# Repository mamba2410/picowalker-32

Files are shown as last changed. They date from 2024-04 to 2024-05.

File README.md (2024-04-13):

# picowalker-32

Thsi repo contains all the designs, schematics, pcb layouts and code for the *picowalker-32* project.

The *picowalker-32* is a modern, open source and faithful recreation of the *Pokewalker* from *Pokemon HeartGold/SoulSilver*.
The goal is to have a device that fully mimics the features and functionality of a *Pokewalker*, except made with modern 
features such as a rechargeable battery, colour screen and an additional flash memory chip to store more data.

The *picowalker-32* is based on the STM32U535 chip, which has far more ram, flash and computing capabilities than the original
processor. Most importantly, its available to purchase, even in small quantities.
Due to the lack of options for screens and batteries, the *picowalker-32* is slightly larger than the original *Pokewalker*.

The software in this repo is designed to be enough to run the [picowalker-core]() code to fully simulate a *Pokewalker*,
however, theres no reason that other software can't be run on it!

The name *picowalker-32* comes from the original *picowalker* concept, a [mintyPi](https://sudomod.com/mintypi-v3-5/) inspired
pokewalker, based on the [Raspberry Pi Pico](https://www.raspberrypi.com/products/raspberry-pi-pico/), hence the *pico* in the name.
The project later evolved into a custom-PCB solution using an STM32 controller for lower power draw. Hence the *-32* suffix.

## What's in this repo

- Design files for the schematics and PCB layout, drawn in KiCAD 7.
- STM32CubeMX configuration for the STM32U545 chip used in the design.
- STM32 code using the STM32 HAL for the drivers and dependencies that the [picowalker-core](https://github.com/mamba2410/picowalker-core) needs to function.
- Developer notes and a bill of materials used in testing.
- Other, miscellaneous notes related to the *picowalker-32* project.

## The state of the project

Currently, the project is in active development.
There are schematics, the start of some code and materials that have been picked out.
The project is being prototyped on a breadboard using the *NUCLEO-U545RE* development board and other
breakout boards for fast prototyping.

Left to do:

- Finish the schematics (power delivery, other checks).
- Finish the driver for the screen.
- Start drivers for the IR, accelerometer, eeprom, flash memory, sound, buttons and others.
- Route the PCB (either a test PCB or directly onto the final form factor).
- Manufacture and test the PCB and iterate on it.

## Development and Contribution

If you want to help develop this project, make sure to read the [development document](./development.md) for instructions 
on how to recreate the project at home.

I encourage you to come join the [Discord](https://discord.gg/dVVnM6f5tP)! This is where most of the discussion happens about the project.
There's also other stuff related to the *Pokewalker* including reverse enginnering and hacking it.

Thanks to all the contributors who have helped out a lot, especially

- Kamp, for doing all the CAD work for the shells, picking out components like the screen and battery (which were really hard to find!) and others.
- Zenith, for help with sprites and images and even recreating most of the coloured ones to work on the walker.
- PoroCYon, for help with schematics, electrical questions and picking a suitable MCU.

## Licensing

I'm not sure about the license, I want this project to be as open and accessible as possible.

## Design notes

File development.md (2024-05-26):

# Developing the picowalker-32

This document contains materials and instructions to help with developing this project.

## Hardware

List of hardware I'm currently using to prototype on a breadboard:

- [NUCLEO-U545RE Nucleo-64 development board](https://www.st.com/en/evaluation-tools/nucleo-u545re-q.html)
- [dwo DO0180PFST05 AMOLED screen](https://www.dwo.net.cn/pd.jsp?fromColId=2&id=11924#_pp=2_2452)
- [Sparkfun BMA400 breakout board](https://www.sparkfun.com/products/21208) (in SPI mode)
- [Mikroe IrDA 3-click Serial-to-IrDA breakout board](https://www.mikroe.com/irda-3-click)
    - Note: any normal IR transceiver will work when directly driven by the STM32
- [Huawei P8 phone speaker](https://www.aliexpress.us/item/2251832745770085.html)
    - Note: this part isn't finalised until we can get it working
- Some SPI EEPROM. Note: this may be removed in the future
    - [M95512 64k (SMD)](https://www.mouser.co.uk/ProductDetail/STMicroelectronics/M95512-DWDW4TP-K?qs=gNDSiZmRJS8kMWQ2whknqA%3D%3D)
    - [25LC512 64k (SMD, breadboard)](https://ww1.microchip.com/downloads/aemDocuments/documents/MPD/ProductDocuments/DataSheets/25LC512-512-Kbit-SPI-Bus-Serial-EEPROM-Data-Sheet-20002065.pdf)
- Some SPI/QSPI 128Mbit flash
    - [IS25WP128 (1.8V, SMD)](https://www.mouser.co.uk/ProductDetail/ISSI/IS25WP128F-JBLE?qs=W0yvOO0ixfF8aDjNpplUZA%3D%3D)

## Software

All software development (except CubeMX stuff) has been done on linux, I don't know how to build and debug on
Windows, sorry.

- [KiCad 7.0](https://www.kicad.org/) for the schematics and PCB layouts (haven't tested with 8.0).
- [SamacSys Library Loader](https://www.samacsys.com/library-loader/) for KiCad models and schematics.
- [STM32CubeMX VERSION 6.10](https://www.st.com/en/development-tools/stm32cubemx.html) for pinout and STM32 MCU initialisation and HAL.
- Neovim/VSCode for all other programming.
- CMake/GNU make for building.
- Linux/WSL for compiling and debugging the code.
- [stlink](https://github.com/stlink-org/stlink) and gdb for on-chip debugging.

## Notes on STM32 stuff

- SPI mode check "Master keep IO state enable" otherwise it fiddles with the clock and misses the first
  bit.

## Guide

Guide is yet to come.

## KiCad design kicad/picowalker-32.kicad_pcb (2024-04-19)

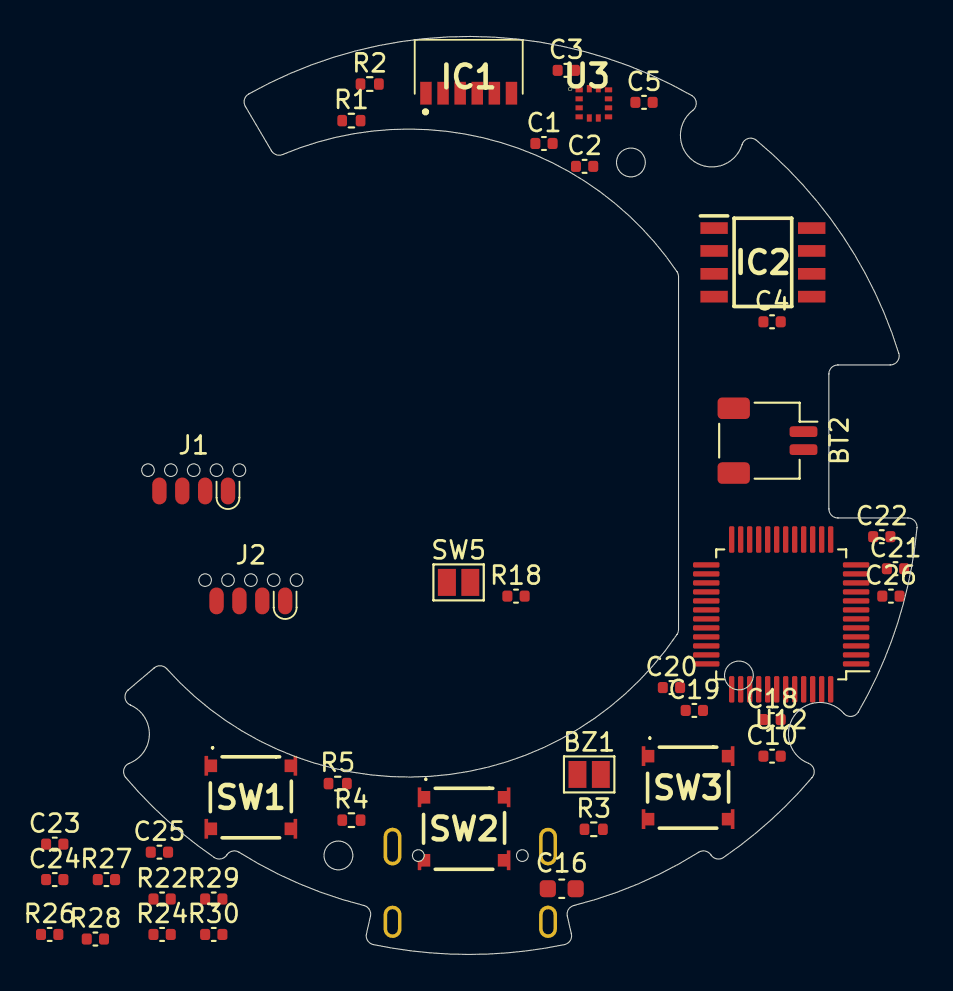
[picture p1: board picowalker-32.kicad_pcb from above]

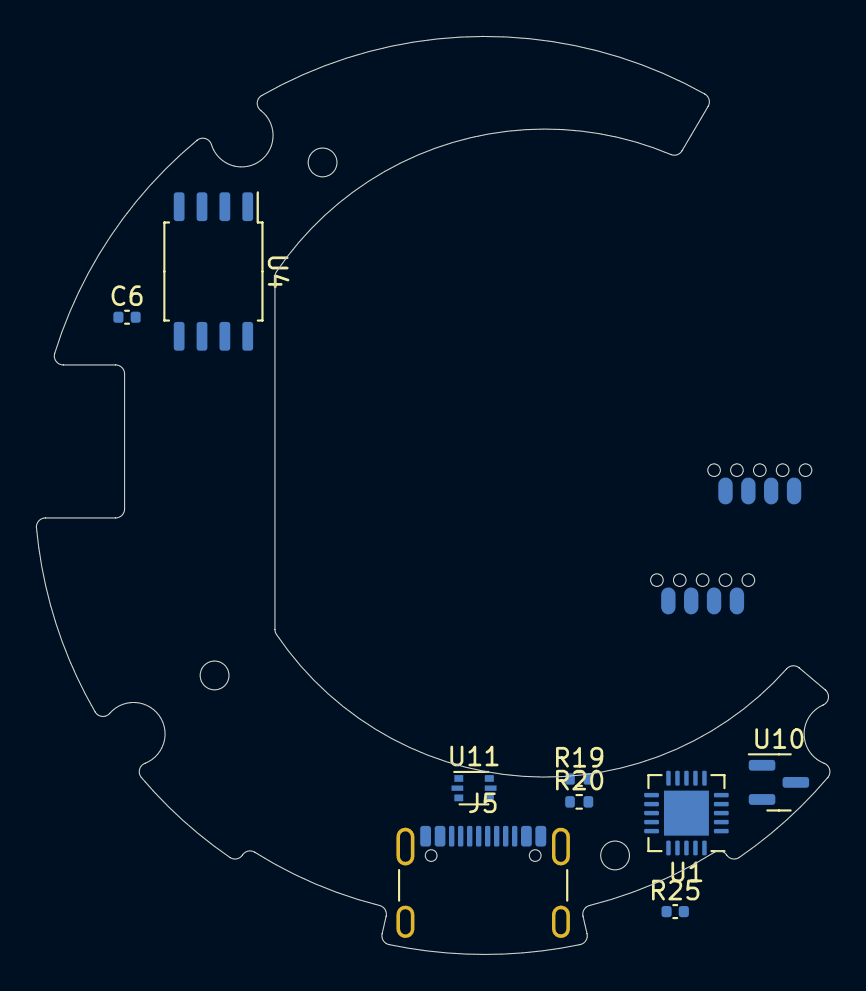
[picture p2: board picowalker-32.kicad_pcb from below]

Board: 2 copper layers, 44.1 x 51.0 mm, 50 parts (9 on the bottom side), 47 nets, no tracks yet.

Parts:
BT2: LPR553535A; JST_SH_SM02B-SRSS-TB_1x02-1MP_P1.00mm_Horizontal
BZ1: Speaker; SolderJumper-2_P1.3mm_Open_Pad1.0x1.5mm
C1, C3, C4, C5, C6: 0.1uF; C_0402_1005Metric
C2, C26: 4.7uF; C_0402_1005Metric
C10, C18, C19, C21: 100nF; C_0402_1005Metric
C16: C; C_0603_1608Metric
C20, C23, C24, C25: 10uF; C_0402_1005Metric
C22: 1uF; C_0402_1005Metric
IC1: TFBS4711-TT1; TFBS4711TT1
IC2: M95512-DRMN8TP_K; SOIC127P600X175-8N
J1: DBG_HDR; SOIC_clipProgSmall
J2: PROGRAM_HDR; SOIC_clipProgSmall
J5: USB_C_Receptacle_USB2.0; USB_C_Receptacle_GCT_USB4105-xx-A_16P_TopMnt_Horizontal
R1: 56R; R_0402_1005Metric
R2: 47R; R_0402_1005Metric
R3, R4, R5: 100k; R_0402_1005Metric
R18, R26: 10k; C_0402_1005Metric
R19, R20: 5k1; R_0402_1005Metric
R22, R24, R25: 100k; C_0402_1005Metric
R27: 20k; C_0402_1005Metric
R28: R; C_0402_1005Metric
R29: 330k; C_0402_1005Metric
R30: 110k; C_0402_1005Metric
SW1, SW2, SW3: SW_Push; TL3315NF100Q
SW5: BOOTSEL; SolderJumper-2_P1.3mm_Open_Pad1.0x1.5mm
U1: MCP73871; QFN-20-1EP_4x4mm_P0.5mm_EP2.5x2.5mm
U3: BMA400; BOSCH_LGA-12
U4: W25Q128JVS; SOIC-8_5.23x5.23mm_P1.27mm
U10: MCP1700x-180xxTT; SOT-23
U11: USBLC6-2P6; SOT-666
U12: STM32U535CET6-modified; LQFP-48_7x7mm_P0.5mm

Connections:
+1V8: C10.2, C18.2, C19.2, C20.2, C21.2, C22.2, R22.2, R24.2, R25.2, SW5.1, U10.2 (VO), U12.1 (VBAT), U12.7 (NRST), U12.9 (VDDA), U12.24 (VDD), U12.36 (VDD), U12.48 (VDD)
/power-control-1.8V/BAT+: BT2.1 (+), C23.1, U1.14 (V_{BAT}), U1.15 (V_{BAT}), U1.16 (V_{BAT_SENSE})
/power-control-1.8V/PWR_SRC: C24.2, U1.1 (OUT), U1.20 (OUT), U10.3 (VI)
/power-control-1.8V/USB_5V: C16.1, C25.2, J5.A4 (VBUS), J5.A9 (VBUS), J5.B4 (VBUS), J5.B9 (VBUS), R29.1, U1.9 (~TE), U1.17 (CE), U1.18 (IN), U1.19 (IN), U11.5 (VBUS)
/power-control-1.8V/USB_DN_RAW: J5.A7 (D-), J5.B7 (D-), U11.1 (I/O1)
/power-control-1.8V/USB_DP_RAW: J5.A6 (D+), J5.B6 (D+), U11.3 (I/O2)
/stm32u5/BOOT0: R18.2, SW5.2, U12.44 (PH3-BOOT0)
ACCEL_CSB: J2.7, U3.10 (CSB), U12.41 (PB5)
ACCEL_INT1: U3.5 (INT1), U12.11 (PA1)
BSTAT1: R24.1, U1.8 (STAT1/~LBO), U12.46 (PB9)
BSTAT2: R22.1, U1.7 (STAT2), U12.39 (PB3)
BUT_L: R3.2, SW1.2, U12.2 (PC13)
BUT_M: R4.2, SW2.2, U12.3 (PC14)
BUT_R: R5.2, SW3.2, U12.4 (PC15)
DBG_RX: J1.6, U12.21 (PB10)
DBG_TX: J1.7, U12.12 (PA2)
EEPROM_CSB: IC2.1 (~S), J2.6, U12.29 (PA8)
FLASH_CSB: J2.8, U4.1 (~CS), U12.38 (PA15)
GND: BZ1.2 (+), C1.1, C2.2, C3.2, C4.2, C5.2, C6.2, C10.1, C18.1, C19.1, C20.1, C21.1, C22.1, C26.2, IC1.4 (SD), IC1.6 (GND), IC2.4 (VSS), J1.4, J1.5, J2.1, R18.1, SW1.1, SW2.1, SW3.1, U3.8 (GNDIO), U3.9 (GND), U4.4 (GND), U12.8 (VSSA), U12.23 (VSS), U12.35 (VSS), U12.47 (VSS)
GNDPWR: BT2.2 (-), C16.2, C23.2, C24.1, C25.1, J5.A1 (GND), J5.A12 (GND), J5.B1 (GND), J5.B12 (GND), J5.S1 (SHIELD), R19.2, R20.2, R26.1, R27.2, R28.2, R30.2, U1.3 (SEL), U1.4 (PROG2), U1.10 (V_{SS}), U1.11 (V_{SS}), U1.21 (V_{SS}), U10.1 (GND), U11.2 (GND)
MISO: IC2.2 (Q), J2.2, U3.1 (SDO), U12.27 (PB14)
MOSI: IC2.5 (D), J2.3, U3.2 (SDX), U12.28 (PB15)
unnamed: C1.2, IC1.5 (VCC1), R2.2
unnamed: C2.1, IC1.1 (VCC2/IRED/ANODE), R1.1
unnamed: J5.A5 (CC1), R19.1
unnamed: J5.B5 (CC2), R20.1
unnamed: R27.1, U1.13 (PROG1)
unnamed: R28.1, U1.12 (PROG3)
unnamed: R26.2, U1.5 (THERM)
unnamed: R29.2, R30.1, U1.2 (VPCC)
unnamed: C26.1, U12.22 (VCAP)
PWR: C3.1, C4.1, C5.1, C6.1, IC2.3 (~W), IC2.7 (~HOLD), IC2.8 (VCC), R1.2, R2.1, R3.1, R4.1, R5.1, U3.3 (VDDIO), U3.7 (VDD), U4.8 (VCC)
QSCK: U4.6 (CLK), U12.13 (PA3)
QSPI0: U4.5 (DI(IO0)), U12.19 (PB1)
QSPI1: U4.2 (DO(IO1)), U12.18 (PB0)
QSPI2: U4.3 (IO2), U12.17 (PA7)
QSPI3: U4.7 (IO3), U12.16 (PA6)
RXDIR: IC1.3 (RXD), U12.31 (PA10)
SCK: IC2.6 (C), J2.4, U3.12 (SCX), U12.26 (PB13)
SCREEN_CSB: J2.5, U12.14 (PA4)
SOUND_SRC: BZ1.1 (-), U12.15 (PA5)
SWCLK: J1.2, U12.37 (PA14)
SWDIO: J1.3, U12.34 (PA13)
TXDIR: IC1.2 (TXD), U12.30 (PA9)
USB_DN: U11.6 (I/O1), U12.32 (PA11)
USB_DP: U11.4 (I/O2), U12.33 (PA12)
~PG: R25.1, U1.6 (~PG), U12.45 (PB8)

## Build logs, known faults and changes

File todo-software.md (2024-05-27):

# TODO - Software

- Configure clocks for STM32.
    - OSPI works when sys clock is 128MHz and OSPI prescaler is 16.
    - Want clocks as low as possible to save power
    - Screen drawing is slow when core speed is slow - use DMA
- Test screen code
- Test accelerometer code
    - how to make device register steps? tapping it doesn't work.
- Test eeprom code
    - Add a `delay_us` function because waiting 1ms between spi actions is wasteful
    - sometimes it times out and fails to read?
- Add M95512 eeprom code
- Add code for flash rom
    - Just a note: both flash memories return data latched on falling edge, but accept data on rising edge
- Test code for IR
    - Write timeout after rx'ing something. idk wtf this is.
- Add code for buttons
    - tweak debounce?
- Add code for speakers
- Figure out how to get device to act as usb slave
- Sleep mode

## Sleep mode

- Screen sleep - Sleep in mode after 30 sec, deep sleep after another 60 sec (arbitrary numbers)
- controller sleep - sleep mode loop and stop 2/3 after 30 sec ? (check limitations of this mode eg. peripheral access)
- 25LC512 has a deep power down, but chip not used in final version
- is25wp128 has a deep power down, enter when in screen deep sleep
- bma400 auto switches between low (1.2uA) and normal power mode. Sleep mode probably useless since we always want to count steps
- IR has a shutdown signal, set that when comms app is not running
    - Idle current <110uA, standby current <1uA, transmitter draws 200-430mA in use
- m95512 auto sleeps when CSB is high

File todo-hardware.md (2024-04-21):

# TODO - Hardware

- Finalise power circuitry
    - Check battery charging
        - Do we really want a non-standard batteyr size? it has better power density
        but will end users be able to order replacements? do we send spares when they order?
    - Check power rails (most 1.8V, some need 3.3V)
            - IR needs 2.4-5.5V operating, can run on `PWR_SRC`
            - Screen VCI and TP_VCC needs 2.7-3.5V, 
            - MAJOR CONCERN: MCU needs 3.3V on VDDUSB which is bonded to VDD in 48-pin package
        - be careful when ordering m95512 M95512-D*W* is 2.5-5.5V, M95512-D*R* is 1.7-5.5V, *F* is 1.8-5.5V (MN is SO8, DW is WSSOP8)
            £0.552 version on mouser will do (M95512-DFMN)
            CHECK VERSION ON SCHEMATIC
        - See ST AN4879 section 2.5 for power - LQFP48 doesn't have external VDDUSB so may need to run MCU at 3.3V? Or get LQFP64 package and give VDDUSB 3.3V
- Do screen circuitry
    - What's required on the pinouts?
    - Are we using touch screen? A: wire it in, but screen has a lens on so it won't be used
    - Check screen voltages
        - VBAT says "3.8V typ, (2.9-4.5V)"
        - VCI (analogue voltage for driver) says "(2.7-3.5V)"
        - VDDIO/IOVCC 1.65-3.3V (prefers 1.8V, will work at 3.3V as tested on breadboard)
        - TP_VCC 2.7-3.4V
- Does flash rom use qspi or normal spi? A: QSPI, can use in SPI mode if needed
- Finalise flash chip, both come in SOIC8 208/VSOP8 208, both are pin-compatible. Have a 0-ohm resistor/bridge to swap power supply?
    - IS25LP128J(B|F)xx - 2.3-3.6V, £1.88/unit, £1.69/10 unit ($2.30/2.07)
    - IS25WP128J(B|F)xx - 1.65-1.95V, £2.03/unit, £1.83/10 unit ($2.50/2.25)
    - W25Q128JV(S|T)x - 2.7-3.6V, £1.38/unit, £1.22/10 unit ($1.72/1.53)
    - Be careful, IO voltage will change with power supply voltage, bear in mind other chips are on the bus. CSB will need to be VCC as well
- Finalise MCU pinouts (nucleo pinouts are different)
    - Do we need external crystal? If so, do we use `OSC32` (PC14,15) or `OSC` (PH0,1)
    - Verify there are no restrictions on interrupt input pins
    - Finalise battery signals (bat sense, power good, bat lo, etc)
    - IR shutdown needs signal, idle power draw is 110uA
- Choose chip packages
    - SOIC8 (2.16mm high) and VSOP8 (1.00mm high) 5.38 x 8.10mm, pins 0.42mm wide, 1.27mm pitch (IS25xP128, W25Q128)
    - SO8N (1.75mm high) 6.20 x 5.00mm, pins 0.48 wide, 1.27mm pitch (m95512)
    - TSSOP8 (1.20mm high) 6.6 x 3.1mm, pins 0.30mm wide, 0.650 pitch (m95512)
- Finalise IR transceiver
    - TFDU4101 is larger
    - TFDU4301 is smaller, slightly cheaper in quantity on mouser uk
    - TFBS4711 is smaller again, even cheaper on mouser uk, same electrical specs
- Layout PCB

## Breadboard prototyping

SMD components breadboard breakout.
Check what's already been bought.

- IR transceiver has 0.5mm wide pins, 1mm apart
- M95512 has 0.380mm pins, 1.27mm apart, min horizontal separation 3.9mm, max 6.0mm, SO8N package
- Both flash chips are 8-pin SOIC 208-mil

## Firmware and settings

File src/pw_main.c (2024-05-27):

#include "main.h"
#include "picowalker-defs.h"

uint8_t *sad_pokewalker;

#include "peripherals.h"
#include "stm32u5xx_hal.h"
#include "stm32u5xx_hal_uart.h"
extern UART_HandleTypeDef DEBUG_UART_HANDLE;

// image of electrode, 32x24 pixels
unsigned char dumps_electrode_small_img_bin[] = {
  0x00, 0x00, 0x00, 0x00, 0x00, 0x00, 0x00, 0x00, 0x00, 0x00, 0x00, 0x00,
  0x00, 0x00, 0x00, 0x00, 0x00, 0x00, 0x00, 0x00, 0xc0, 0xc0, 0x40, 0x40,
  0x20, 0x20, 0x20, 0x20, 0x10, 0x10, 0x10, 0x10, 0x10, 0x10, 0x10, 0x10,
  0x20, 0x20, 0x20, 0x20, 0x40, 0x40, 0xc0, 0xc0, 0x00, 0x00, 0x00, 0x00,
  0x00, 0x00, 0x00, 0x00, 0x00, 0x00, 0x00, 0x00, 0x00, 0x00, 0x00, 0x00,
  0x00, 0x00, 0x00, 0x00, 0x00, 0x00, 0x00, 0x00, 0x00, 0x00, 0x00, 0x00,
  0x00, 0x00, 0x00, 0x00, 0x00, 0x00, 0x00, 0x00, 0x3c, 0x3c, 0xcb, 0xfb,
  0xb0, 0x70, 0x00, 0xc0, 0x00, 0xc0, 0x10, 0x90, 0x60, 0xe0, 0x10, 0x90,
  0x08, 0x88, 0x00, 0x80, 0x00, 0xc0, 0x00, 0xc0, 0x00, 0xe0, 0x80, 0x70,
  0xc3, 0xff, 0x3c, 0x3c, 0x00, 0x00, 0x00, 0x00, 0x00, 0x00, 0x00, 0x00,
  0x00, 0x00, 0x00, 0x00, 0x00, 0x00, 0x00, 0x00, 0x00, 0x00, 0x00, 0x00,
  0x00, 0x00, 0x00, 0x00, 0x00, 0x00, 0x00, 0x00, 0x00, 0x00, 0x00, 0x00,
  0x00, 0x00, 0x00, 0x00, 0x03, 0x03, 0x03, 0x02, 0x07, 0x04, 0x06, 0x05,
  0x0e, 0x09, 0x0e, 0x09, 0x0e, 0x09, 0x0e, 0x09, 0x06, 0x05, 0x07, 0x04,
  0x03, 0x02, 0x03, 0x03, 0x00, 0x00, 0x00, 0x00, 0x00, 0x00, 0x00, 0x00,
  0x00, 0x00, 0x00, 0x00, 0x00, 0x00, 0x00, 0x00, 0x00, 0x00, 0x00, 0x00
};
unsigned int dumps_electrode_small_img_bin_len = 192;

unsigned char dumps_furret_large_img_bin[] = {
  0x00, 0x00, 0x00, 0x00, 0x00, 0x00, 0x00, 0x00, 0x00, 0x00, 0x00, 0x00,
  0x00, 0x00, 0x00, 0x00, 0x00, 0x00, 0x00, 0x00, 0x00, 0x00, 0x00, 0x00,
  0x00, 0x00, 0x00, 0x00, 0x00, 0x00, 0xc0, 0xc0, 0xf0, 0x30, 0xc8, 0x20,
  0xf8, 0xf8, 0x80, 0x80, 0x80, 0x00, 0xc0, 0x40, 0xc0, 0x40, 0xc0, 0x40,
  0xc0, 0x40, 0xc0, 0x40, 0xe0, 0x20, 0xe0, 0x20, 0xf0, 0x10, 0xf8, 0x00,
  0xe8, 0x00, 0xe4, 0x00, 0xf0, 0xc4, 0x32, 0x38, 0x0e, 0x0e, 0x00, 0x00,
  0x00, 0x00, 0x00, 0x00, 0x00, 0x00, 0x00, 0x00, 0x00, 0x00, 0x00, 0x00,
  0x00, 0x00, 0x00, 0x00, 0x00, 0x00, 0x00, 0x00, 0x00, 0x00, 0x00, 0x00,
  0x00, 0x00, 0x00, 0x00, 0x00, 0x00, 0x00, 0x00, 0x00, 0x00, 0x00, 0x00,
  0x00, 0x00, 0x00, 0x00, 0x00, 0x00, 0x00, 0x00, 0x00, 0x00, 0x00, 0x00,
  0x00, 0x00, 0x00, 0x00, 0x00, 0x00, 0x00, 0x00, 0x00, 0x00, 0x00, 0x00,
  0x00, 0x00, 0x00, 0x00, 0x00, 0x00, 0x00, 0x00, 0x00, 0x00, 0x00, 0x00,
  0x00, 0x00, 0x00, 0x00, 0x00, 0x00, 0x00, 0x00, 0x00, 0x00, 0xe0, 0xe0,
  0xdc, 0x90, 0x07, 0x03, 0x0f, 0x00, 0x9f, 0x81, 0x8f, 0x90, 0x07, 0x08,
  0x07, 0x00, 0x03, 0x04, 0x33, 0x78, 0x69, 0x4a, 0x31, 0x7a, 0x81, 0x82,
  0x83, 0x84, 0x3f, 0x80, 0x7f, 0x00, 0xff, 0x00, 0xff, 0x02, 0xff, 0x07,
  0xf8, 0x18, 0xe0, 0x60, 0x80, 0x80, 0x00, 0x00, 0x00, 0x00, 0x00, 0x00,
  0x00, 0x00, 0x00, 0x00, 0x00, 0x00, 0x00, 0x00, 0x00, 0x00, 0x00, 0x00,
  0x00, 0x00, 0x00, 0x00, 0x00, 0x00, 0x00, 0x00, 0x00, 0x00, 0x00, 0x00,
  0x00, 0x00, 0x00, 0x00, 0x00, 0x00, 0x00, 0x00, 0x00, 0x00, 0x00, 0x00,
  0x00, 0x00, 0x00, 0x00, 0x00, 0x00, 0x00, 0x00, 0x00, 0x00, 0x00, 0x00,
  0x00, 0x00, 0x00, 0x00, 0x00, 0x00, 0x00, 0x00, 0x00, 0x00, 0x00, 0x00,
  0x00, 0x00, 0x00, 0x00, 0x00, 0x00, 0x00, 0x00, 0x00, 0x00, 0x00, 0x00,
  0x00, 0x00, 0x00, 0x00, 0x00, 0x00, 0x03, 0x03, 0x0c, 0x0c, 0x10, 0x18,
  0x23, 0x31, 0x27, 0x23, 0x45, 0x63, 0x83, 0xe1, 0x00, 0xc0, 0x00, 0xc0,
  0x00, 0xc0, 0x00, 0xc0, 0x02, 0x42, 0x06, 0x02, 0x05, 0x02, 0x01, 0x00,
  0x00, 0x00, 0x00, 0x01, 0x03, 0x04, 0x1f, 0x20, 0xff, 0x00, 0xff, 0x00,
  0xff, 0x07, 0xf8, 0xf8, 0x00, 0x00, 0x00, 0x00, 0x00, 0x00, 0x80, 0x80,
  0x40, 0xc0, 0x20, 0x60, 0x10, 0x00, 0x08, 0x00, 0x04, 0x00, 0x04, 0x00,
  0x02, 0x00, 0x02, 0x00, 0x02, 0x00, 0x01, 0x00, 0x01, 0x80, 0x01, 0x80,
  0x01, 0xc0, 0x01, 0xe0, 0x01, 0xe0, 0x0d, 0xf4, 0x4a, 0xf2, 0xa8, 0xb0,
  0x18, 0x18, 0x00, 0x00, 0x00, 0x00, 0x00, 0x00, 0x00, 0x00, 0x00, 0x00,
  0x00, 0x00, 0x00, 0x00, 0x00, 0x00, 0x00, 0x00, 0x00, 0x00, 0x00, 0x00,
  0x00, 0x00, 0x00, 0x00, 0x00, 0x00, 0x00, 0x00, 0x00, 0x00, 0x00, 0x00,
  0x00, 0x00, 0x00, 0x00, 0x00, 0x00, 0x00, 0x00, 0x30, 0x30, 0x78, 0x48,
  0xf8, 0x88, 0x18, 0xc8, 0x93, 0x53, 0x7c, 0x03, 0x00, 0x01, 0x00, 0x00,
  0x00, 0x00, 0x00, 0x00, 0x00, 0x00, 0x18, 0x38, 0x7c, 0x64, 0xbc, 0xcc,
  0x1c, 0xe4, 0x08, 0xc8, 0x10, 0x91, 0x07, 0xe0, 0xff, 0x00, 0xff, 0x01,
  0xfe, 0xfe, 0xd8, 0xc8, 0xce, 0xc6, 0xcf, 0xc1, 0x8f, 0xc0, 0x8f, 0xc0,
  0x8f, 0xc0, 0x0f, 0xe0, 0x1f, 0xf0, 0x1f, 0xf0, 0x3e, 0xf8, 0x7e, 0xf8,
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
};
unsigned int dumps_furret_large_img_bin_len = 1536;

/*
 * ===================================
 * STUBS PLEASE FILL IN
 * ===================================
 */
void pw_ir_delay_ms(size_t delay) {
    HAL_Delay(delay);
}

void pw_flash_read() {

}

extern TIM_HandleTypeDef htim1;
uint32_t pw_now_us() {
    return htim1.Instance->CNT;
}

void picowalker_main() {

    HAL_GPIO_WritePin(ACCEL_CSB_PORT, ACCEL_CSB_PIN, GPIO_PIN_SET);
    HAL_GPIO_WritePin(EEPROM_CSB_PORT, EEPROM_CSB_PIN, GPIO_PIN_SET);

    walker_entry();

    /*
    pw_log_init();
    pw_screen_init();
    pw_eeprom_init();
    //pw_accel_init();
    pw_ir_init();
    pw_button_init();

    pw_img_t img = {
        .width = 64,
        .height = 48,
        .data = dumps_furret_large_img_bin
    };

    //screen_clear_area(0, 0, 200, 200, 0xf83f); // RGB=(1, 1, 1)
    //screen_clear_area(0, 0, 100, 100, 0xe03f);

    uint8_t buf[16] = {0};
    uint8_t rxbuf[16] = {0};

    int colour = 0x87e1; // works
    int boop = 0;
    while(1) {
        //pw_eeprom_read(0x0000, buf, 8);
        //pw_log(4, "nintendo string: %s\r\n", buf);

        uint32_t new_steps = pw_accel_get_new_steps();
        pw_log(4, "got new steps %d\r\n", new_steps);

        rxbuf[0] = 0;
        int recv = pw_ir_read(rxbuf, 16);
        if(recv > 0) {
            pw_log(4, "ir read: 0x%02x\r\n", rxbuf[0] ^ 0xaa);
        }

        buf[0] = 0xfc ^ 0xaa;
        pw_ir_write(buf, 1);

        pw_screen_draw_img(&img, 32, 0);
        img.data = dumps_furret_large_img_bin + boop*768;
        boop = (boop+1)%2;
        HAL_GPIO_TogglePin(LED_GREEN_GPIO_Port, LED_GREEN_Pin);
        //screen_clear_area(300, 300, 64, 96, colour);
        colour ^= 0xffff;
        HAL_Delay(500);
    }

    */
}

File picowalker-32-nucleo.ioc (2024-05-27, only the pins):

Mcu.UserName=STM32U545RETxQ
PA0.GPIO_Label=IrDA_TX
PA0.Signal=UART4_TX
PA1.GPIO_Label=IrDA_RX
PA1.Signal=UART4_RX
PA10.Signal=USART1_RX
PA2.Signal=OCTOSPI1_NCS
PA3.Signal=OCTOSPI1_CLK
PA4.Signal=COMP_DAC11_group
PA5.GPIO_Label=LED_GREEN
PA5.Signal=GPIO_Output
PA6.Signal=OCTOSPI1_IO3
PA7.Signal=OCTOSPI1_IO2
PA8.GPIO_Label=EEPROM_CSB
PA8.Signal=GPIO_Output
PA9.Signal=USART1_TX
PB0.Signal=OCTOSPI1_IO1
PB1.Signal=OCTOSPI1_IO0
PB13.Signal=SPI2_SCK
PB14.Signal=SPI2_MISO
PB15.Signal=SPI2_MOSI
PB2.Signal=PWR_WKUP1
PB5.GPIO_Label=ACCEL_CSB
PB5.Signal=GPIO_Output
PB6.Signal=I2C1_SCL
PB7.Signal=I2C1_SDA
PB8.GPIO_Label=BAT_LO
PB8.Signal=GPIO_Input
PC0.GPIO_Label=SCREEN_RST
PC0.Signal=GPIO_Output
PC10.GPIO_Label=BUTL
PC10.Signal=GPXTI10
PC11.GPIO_Label=BUTM
PC11.Signal=GPXTI11
PC12.GPIO_Label=BUTR
PC12.Signal=GPXTI12
PC13.GPIO_Label=USER_BUTTON
PC13.Signal=GPXTI13
PC2.Signal=ADC1_IN3
PH3-BOOT0.GPIO_Label=BOOT0
PH3-BOOT0.Signal=GPIO_Input

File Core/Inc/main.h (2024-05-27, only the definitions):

#define USER_BUTTON_Pin GPIO_PIN_13
#define USER_BUTTON_GPIO_Port GPIOC
#define USER_BUTTON_EXTI_IRQn EXTI13_IRQn
#define ACCEL_INT1_Pin GPIO_PIN_1
#define ACCEL_INT1_GPIO_Port GPIOH
#define ACCEL_INT1_EXTI_IRQn EXTI1_IRQn
#define SCREEN_RST_Pin GPIO_PIN_0
#define SCREEN_RST_GPIO_Port GPIOC
#define IrDA_TX_Pin GPIO_PIN_0
#define IrDA_TX_GPIO_Port GPIOA
#define IrDA_RX_Pin GPIO_PIN_1
#define IrDA_RX_GPIO_Port GPIOA
#define LED_GREEN_Pin GPIO_PIN_5
#define LED_GREEN_GPIO_Port GPIOA
#define EEPROM_CSB_Pin GPIO_PIN_8
#define EEPROM_CSB_GPIO_Port GPIOA
#define FLASH_CSB_Pin GPIO_PIN_15
#define FLASH_CSB_GPIO_Port GPIOA
#define BUTL_Pin GPIO_PIN_10
#define BUTL_GPIO_Port GPIOC
#define BUTL_EXTI_IRQn EXTI10_IRQn
#define BUTM_Pin GPIO_PIN_11
#define BUTM_GPIO_Port GPIOC
#define BUTM_EXTI_IRQn EXTI11_IRQn
#define BUTR_Pin GPIO_PIN_12
#define BUTR_GPIO_Port GPIOC
#define BUTR_EXTI_IRQn EXTI12_IRQn
#define ACCEL_CSB_Pin GPIO_PIN_5
#define ACCEL_CSB_GPIO_Port GPIOB
#define BOOT0_Pin GPIO_PIN_3
#define BOOT0_GPIO_Port GPIOH
#define BAT_LO_Pin GPIO_PIN_8
#define BAT_LO_GPIO_Port GPIOB

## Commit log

2024-04-13 Add kicad files
    [picowalker-32.kicad_sch, power-control-1.8V.kicad_sch, screen.kicad_sch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]
2024-04-13 Update schematic and add basic PCB layout
    [picowalker-32.kicad_pcb, picowalker-32.kicad_sch, power-control-1.8V.kicad_sch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]
2024-04-13 Change schematic MCU pinouts
    [picowalker-32.kicad_pcb, picowalker-32.kicad_sch, stm32u5.kicad_sch]
2024-04-18 Add accelerometer code
2024-04-18 oops, accel in the wrong folder
    [accel_u545_bma400.c]
2024-04-18 fix mega typo in function call
    [accel_u545_bma400.c]
2024-04-18 add accelerometer functions to picowalker-defs.h
2024-04-18 progress on ir code, missing timers
    [ir_u545_irda.c, ir_u545_uart.c]
2024-04-18 make a start on flash spi code
2024-04-19 investigating hardware voltages and sleep mode
2024-04-19 comments about power, changed eeprom and flash packages
    [picowalker-32.kicad_pcb, picowalker-32.kicad_sch, power-control-1.8V.kicad_sch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]
2024-04-21 playing with battery/power circuit
    [picowalker-32.kicad_sch, power-control-1.8V.kicad_sch]
2024-05-25 fix screen compiler errors
    [screen_u545_dwo.c]
2024-05-26 set uart4 to uart mode for irda 3 click
2024-05-26 specify stm32cubemx version
2024-05-26 eeprom spi works at 1MHz, need to fix 1ms delays
    [eeprom_u545_25lc512.c, picowalker-32-nucleo.ioc, pw_main.c]
2024-05-26 spi works properly with accel and eeprom
2024-05-27 added IR code, transmit broken
    [ir_u545_uart.c, peripherals.h, picowalker-32-nucleo.ioc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]
2024-05-27 add button interrupt code
2024-05-27 buttons now actually call picowalker-core callback
2024-05-27 add log for when accel chipid check fails
    [accel_u545_bma400.c]
2024-05-27 add accel int pin
2024-07-21 hw: change to 3v3 LDO and remove unnecessary MCU pins
    [picowalker-32.kicad_sch, power-control-3.3v.kicad_sch, stm32u5.kicad_sch]
2024-07-21 hw: update power symbols, clean up some power circuitry
    [picowalker-32.kicad_sch, power-control-3.3v.kicad_sch, screen.kicad_sch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]
2024-07-21 hw: more consideration on battery circuit
    [power-control-3.3v.kicad_sch]

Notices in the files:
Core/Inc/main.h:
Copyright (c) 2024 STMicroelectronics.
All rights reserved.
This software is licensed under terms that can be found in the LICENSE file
